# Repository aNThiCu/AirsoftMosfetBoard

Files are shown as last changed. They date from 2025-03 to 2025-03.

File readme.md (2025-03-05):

This is the latest stable version that currently works on my airsoft replica without any problems.

Development was stalled for a while because of a high speed motor that drew a ton of amps on start-up , frying some of my mosfets randomly. Low TPA motors (11 TPA in my case) are not advised for this ETU version
for multiple reasons:

	-random failure of mosfet
	-if the battery doesn't have enough discharge rate the microcontroller will restart on trigger pull
	voltage drop too big for LDO to work.

Even though there is a PMOS for active brake , i do not use it in my code for this version as i want to get a perfect NMOS only version first.
You can just ignore the parts linked to the active brake feature , list of references:

	-R9,R7,R8
	-Q5,Q8

Diode for flywheel protection is not necessary , i personally don't use it because i haven't had time to test the diode with the new motor, old motor always made it go up in flames , 
had better chances of survival without it. 
Serial communication for easier debugging doesn't work for now.

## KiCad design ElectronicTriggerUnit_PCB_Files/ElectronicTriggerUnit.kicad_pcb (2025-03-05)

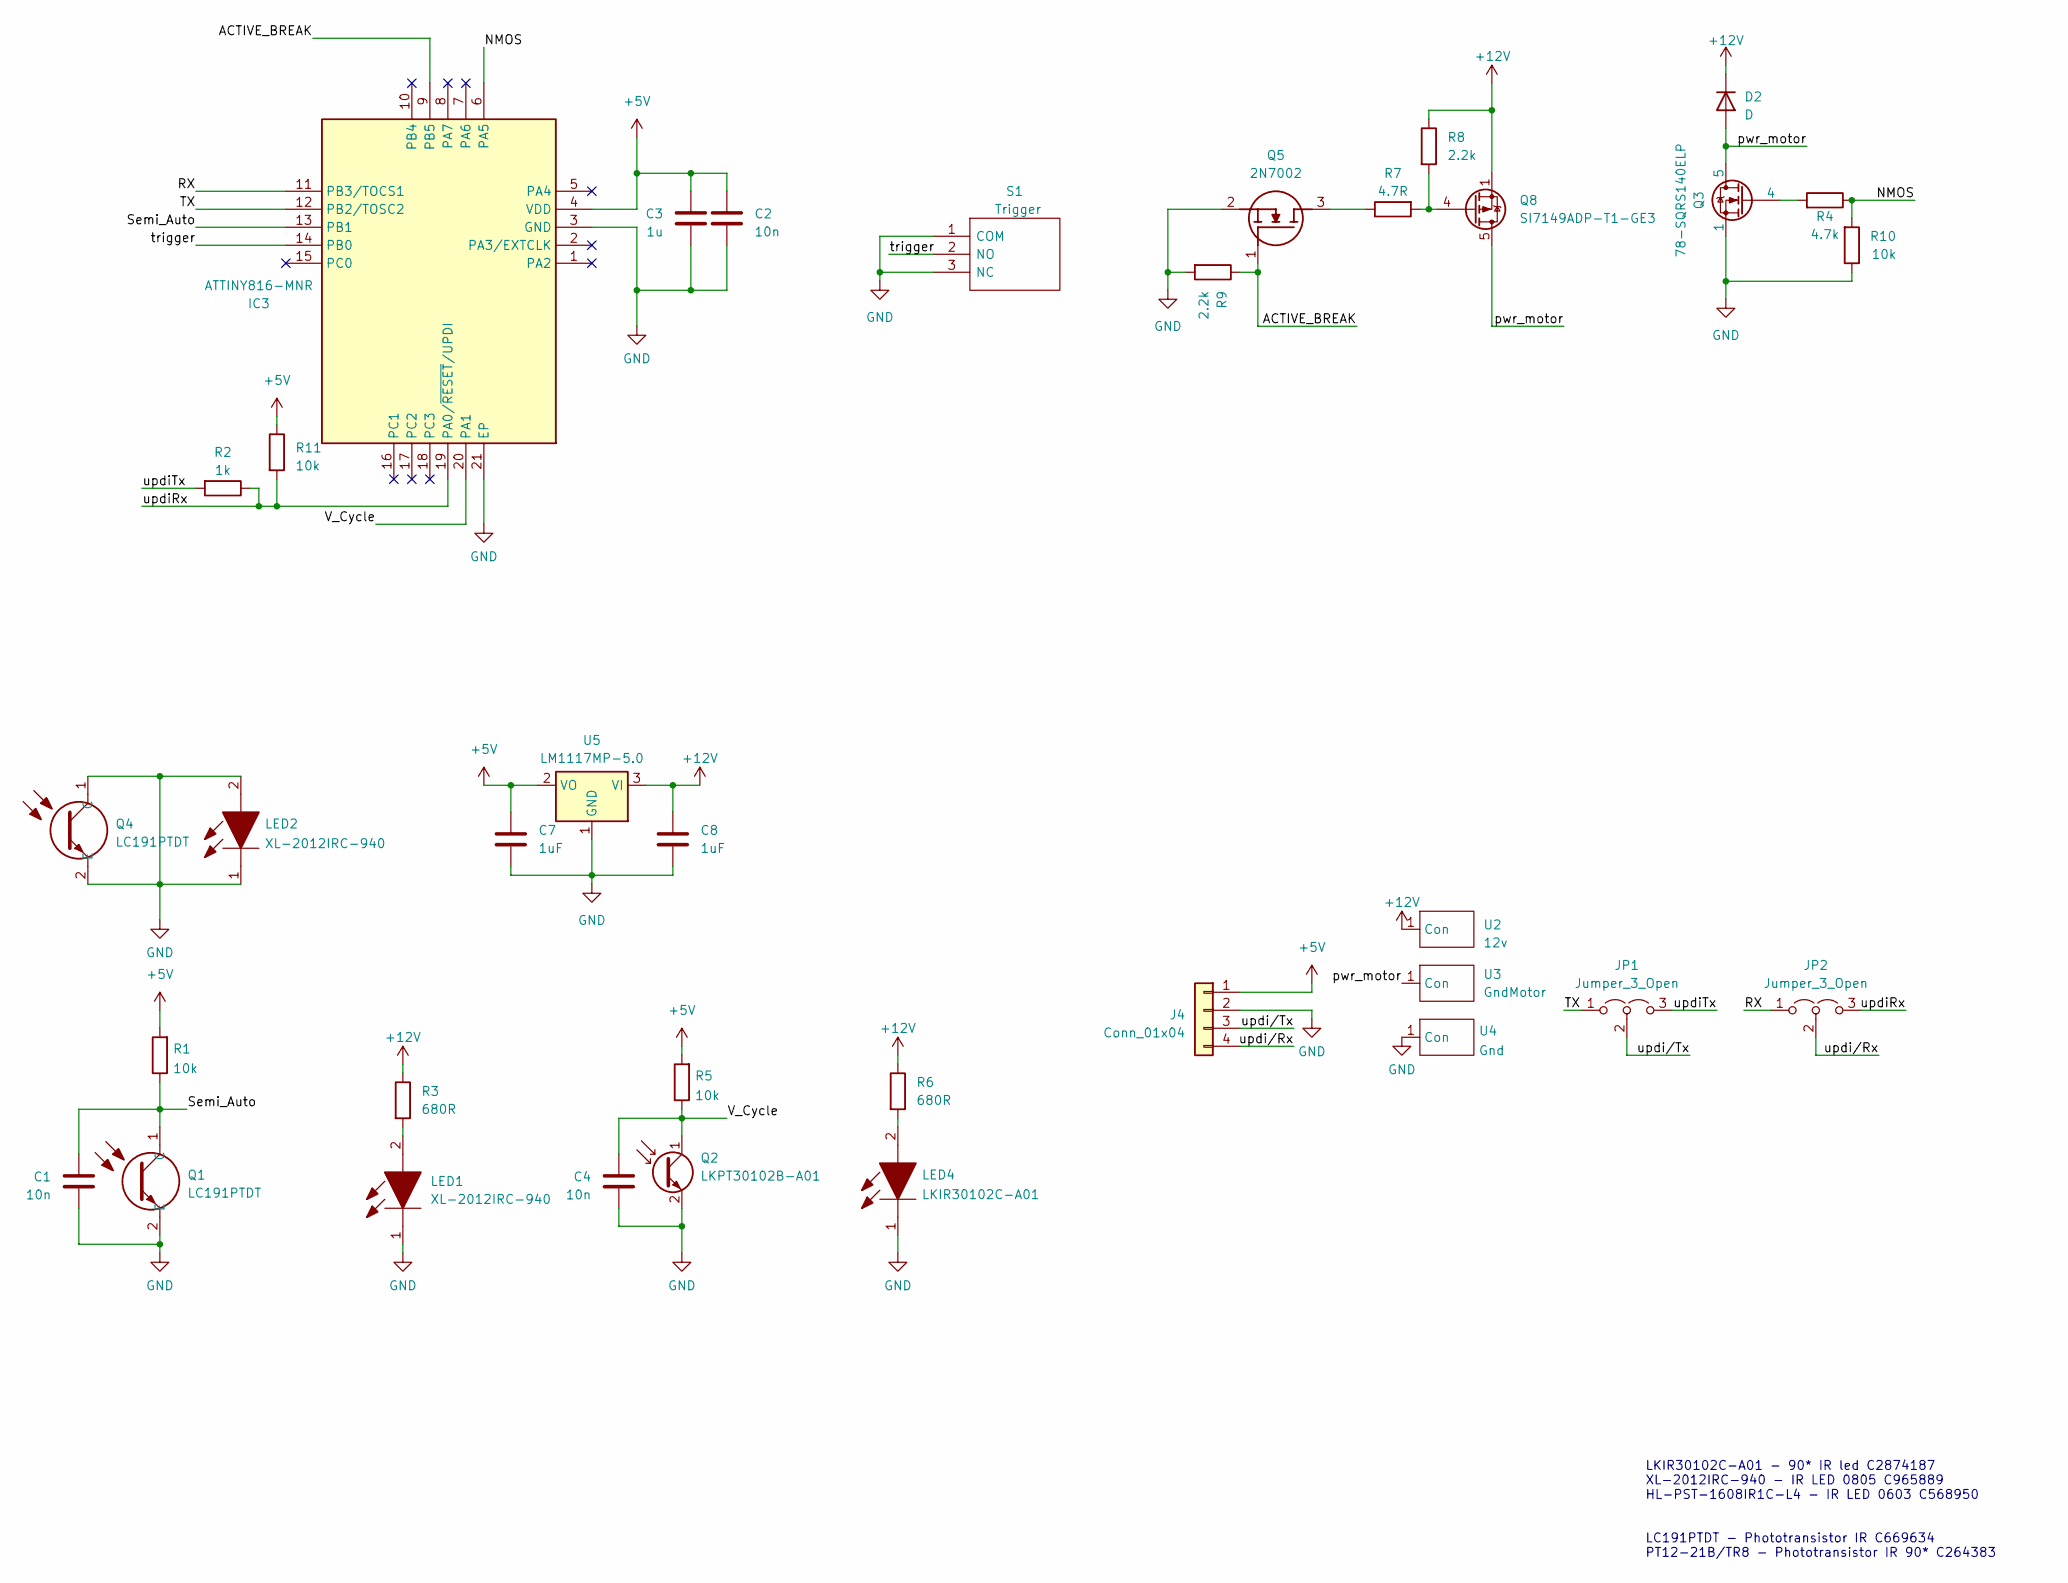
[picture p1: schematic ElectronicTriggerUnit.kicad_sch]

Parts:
C1, C2, C4: 10n; C_0402_1005Metric
C3: 1u; C_0402_1005Metric
C7, C8: 1uF; C_0402_1005Metric
D2: D; SBR3U60P1Q7
IC3: ATTINY816-MNR; QFN40P300X300X90-21N; Mouser Part Number 579-ATTINY816-MNR
J4: Conn_01x04; PinHeader_1x04_P2.54mm_Vertical
JP1, JP2: Jumper_3_Open; SolderJumper-3_P1.3mm_Open_RoundedPad1.0x1.5mm
LED1, LED2: XL-2012IRC-940; LEDC2012X105N; Mouser Part Number 604-APTD2012SF4C
LED4: LKIR30102C-A01; APA3010P3C; Mouser Part Number 755-CSL1501RW1
Q1, Q4: LC191PTDT; AP1608P1CP22; Mouser Part Number 604-AP1608P1C-P22
Q2: LKPT30102B-A01; APA3010P3C
Q3: 78-SQRS140ELP; POWERPAKSO-8
Q5: 2N7002; SOT96P240X120-3N; Mouser Part Number 512-2N7002
Q8: SI7149ADP-T1-GE3; POWERPAKSO-8
R1, R5, R10, R11: 10k; R_0402_1005Metric
R2: 1k; R_0402_1005Metric
R3, R6: 680R; R_0402_1005Metric
R4: 4.7k; R_0402_1005Metric
R7: 4.7R; R_0402_1005Metric
R8, R9: 2.2k; R_0402_1005Metric
S1: Trigger; 463092691402; Mouser Part Number 710-463092691402
U2: 12v; Copper_pad
U3: GndMotor; Copper_pad
U4: Gnd; Copper_pad
U5: LM1117MP-5.0; SOT-223-3_TabPin2

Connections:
+5V: C2.1, C3.1, C7.2, IC3.4 (VDD), J4.1, R1.2, R5.2, R11.1, U5.2 (VO)
+12V: C8.2, D2.1 (K), Q8.1 (S), Q8.2 (S), Q8.3 (S), R3.1, R6.1, R8.1, U2.1 (Con), U5.3 (VI)
/ACTIVE_BREAK: IC3.9 (PB5), Q5.1 (G), R9.1
/NMOS: IC3.6 (PA5), R4.1, R10.2
/RX: IC3.11 (PB3/TOCS1), JP2.1 (A)
/Semi_Auto: C1.1, IC3.13 (PB1), Q1.1 (C), R1.1
/TX: IC3.12 (PB2/TOSC2), JP1.1 (A)
/V_Cycle: C4.1, IC3.20 (PA1), Q2.1 (C), R5.1
/pwr_motor: D2.2 (A), Q3.5, Q3.6, Q3.7, Q3.8, Q3.9, Q8.5 (D), Q8.6, Q8.7, Q8.8, Q8.9, U3.1 (Con)
/trigger: IC3.14 (PB0), S1.2 (NO)
/updiRx: IC3.19 (PA0/~RESET/UPDI), JP2.3 (B), R2.1, R11.2
/updiTx: JP1.3 (B), R2.2
/updi/Rx: J4.4, JP2.2 (C)
/updi/Tx: J4.3, JP1.2 (C)
GND: C1.2, C2.2, C3.2, C4.2, C7.1, C8.1, IC3.3 (GND), IC3.21 (EP), J4.2, LED1.1, LED2.1, LED2.2, LED4.1, Q1.2 (E), Q2.2 (E), Q3.1, Q3.2, Q3.3, Q4.1 (C), Q4.2 (E), Q5.2 (S), R9.2, R10.1, S1.1 (COM), S1.3 (NC), U4.1 (Con), U5.1 (GND)
unnamed: LED1.2, R3.2
unnamed: LED4.2, R6.2
unnamed: Q3.4, R4.2
unnamed: Q5.3 (D), R7.1
unnamed: Q8.4 (G), R7.2, R8.2

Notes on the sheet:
LKIR30102C-A01 - 90* IR led C2874187 XL-2012IRC-940 - IR LED 0805 C965889 HL-PST-1608IR1C-L4 - IR LED 0603 C568950 LC191PTDT - Phototransistor IR C669634 PT12-21B/TR8 - Phototransistor IR 90* C264383

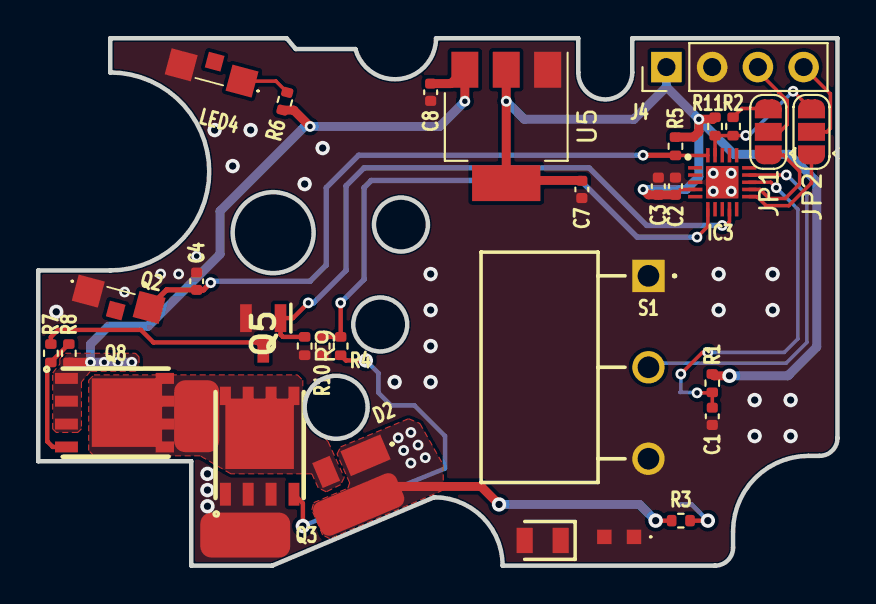
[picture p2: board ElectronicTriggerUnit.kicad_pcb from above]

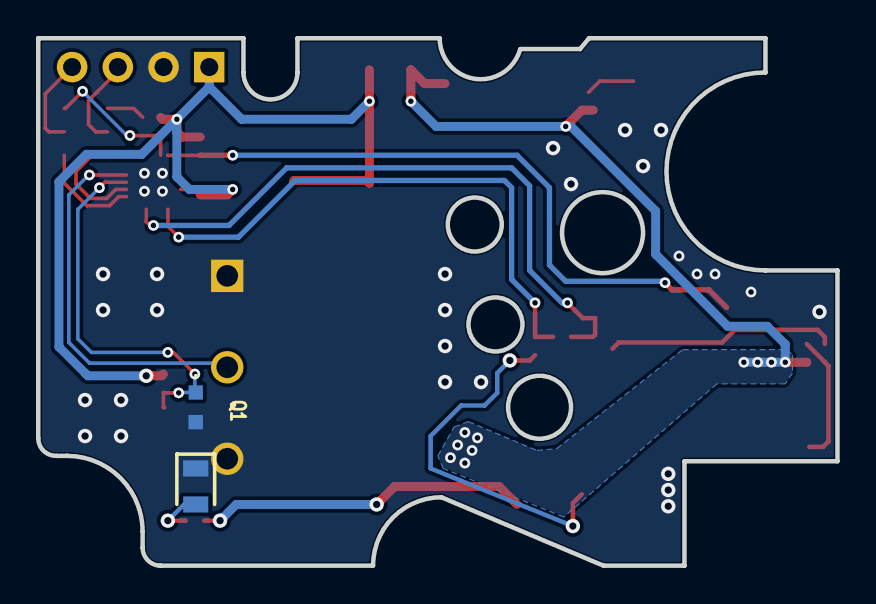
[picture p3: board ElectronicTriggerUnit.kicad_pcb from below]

Board: 2 copper layers, 44.4 x 29.3 mm, 36 parts (2 on the bottom side), 20 nets.

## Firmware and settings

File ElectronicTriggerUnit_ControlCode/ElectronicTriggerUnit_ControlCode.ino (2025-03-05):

//MotorStates
#define STANDBY 0
#define MOTORENABLE 1
#define MOTORFULLPOWER 2
#define MOTORDISABLE 3
//SelectorStates
#define SEMI 0
#define AUTO 1
//Parameters
#define DEBOUNCETIME 20           //increase if debounce isn't properly handled
#define SELECTORLEDTHRESHOLD 55   //led and phototransistor lottery here , hard to figure out without a serial connection 
////pins
int triggerPin = PIN_PB0;
int cyclePin = PIN_PA1;
int modePin = PIN_PB1;
int motorGroundPlane = PIN_PA5;
//logic
volatile int motorState = STANDBY;
int selectorState = SEMI;
//debounceTiming
volatile unsigned long last_millis = 0;


void setup() {
  //Input Init
  pinMode(triggerPin, INPUT_PULLUP);
  pinMode(cyclePin, INPUT);
  pinMode(modePin, INPUT);
  //Output Init
  pinMode(motorGroundPlane, OUTPUT);
  digitalWrite(motorGroundPlane,LOW);

  attachInterrupt(digitalPinToInterrupt(triggerPin), flag_trigger, FALLING);
  attachInterrupt(digitalPinToInterrupt(cyclePin), flag_cycle, RISING);
}

void flag_trigger() {
  if (motorState == STANDBY && millis() - last_millis > DEBOUNCETIME) {
    motorState = MOTORENABLE;
    last_millis = millis();
  }
}

void flag_cycle() {
  if (motorState == MOTORFULLPOWER)
    motorState = MOTORDISABLE;
}

void motor_on() {
  digitalWrite(motorGroundPlane, HIGH);
  motorState = MOTORFULLPOWER;
}

void motor_off() {
  if (analogRead(modePin) <= SELECTORLEDTHRESHOLD) selectorState = SEMI;  //Comment these 2 lines if
  else selectorState = AUTO;                                              //you don't want to use the selector
  switch (selectorState) {
    case SEMI:
      digitalWrite(motorGroundPlane, LOW);
      motorState = STANDBY;
      break;
    case AUTO:
      if (digitalRead(triggerPin) == 1) {
        digitalWrite(motorGroundPlane, LOW);
        motorState = STANDBY;
      }
      break;
  }
}

void loop() {
  if (motorState == MOTORENABLE) motor_on();
  else if (motorState == MOTORDISABLE) motor_off();
}

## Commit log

2023-09-03 Add files via upload
    The shooting logic value has been replaced by detaching and attaching interrupts in order to obtain the same results.
2024-01-30 PCB Files
    [PCBTRIGGERASSEMBLY-B_Cu.gbr, PCBTRIGGERASSEMBLY-B_Mask.gbr, PCBTRIGGERASSEMBLY-B_Paste.gbr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]
2025-03-05 complete redo
    [PCBTRIGGERASSEMBLY-B_Cu.gbr, PCBTRIGGERASSEMBLY-B_Mask.gbr, PCBTRIGGERASSEMBLY-B_Paste.gbr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]
2025-03-05 redo of project
    [ElectronicTriggerUnit-B_Cu.gbr, ElectronicTriggerUnit-B_Mask.gbr, ElectronicTriggerUnit-B_Paste.gbr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]
